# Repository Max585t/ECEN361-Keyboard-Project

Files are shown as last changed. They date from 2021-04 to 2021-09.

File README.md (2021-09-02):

# ECEN361-Keyboard-Project

This project is built on top of Redox by Mattia Dal Ben (https://github.com/mattdibi/redox-keyboard) and KMK by @klardotsh and @kdb424 (https://github.com/KMKfw/kmk_firmware)

## Code
The code I wrote for this project can be found in code.py. This file is what the circuitpython device (Pi Pico in this case) actually runs.

## Modifications
For this project, I had to make modifications to both Redox and KMK. Here are my changes to the Redox base plate.



Here are the changes I made to KMK

Original:
```python
#led.py
import pulseio
...
self.led = pulseio.PWMOut(led_pin)

#kmk_keyboard.py
def init_uart(self, pin, timeout=20):
  if self.is_target:
    return busio.UART(tx=None, rx=pin, timeout=timeout)
  else:
    return busio.UART(tx=pin, rx=None, timeout=timeout)
```
Mine:
```python
#led.py
import pwmio
...
self.led = pwmio.PWMOut(led_pin)
    
#kmk_keyboard.py
def init_uart(self, pin, timeout=20):
  if self.is_target:
    return busio.UART(tx=None, rx=pin[1], timeout=timeout)
  else:
    return busio.UART(tx=pin[0], rx=None, timeout=timeout)
```

## Schematic
Keyboard Schematic
It is important to note that the GND pin on the USB breakout board be connected directly to TP1 and not any of the Pico's other GND pins. If USB ground is not connected to TP1, USB type C will not work. 
Also, the even though the diodes are on the rows, they must be defined in KMK as being on columns. This is because the diode orientation used in the circuit is for pulling pins low, but KMK pulls its pins high. 

## Pictures



note: final base plate not shown


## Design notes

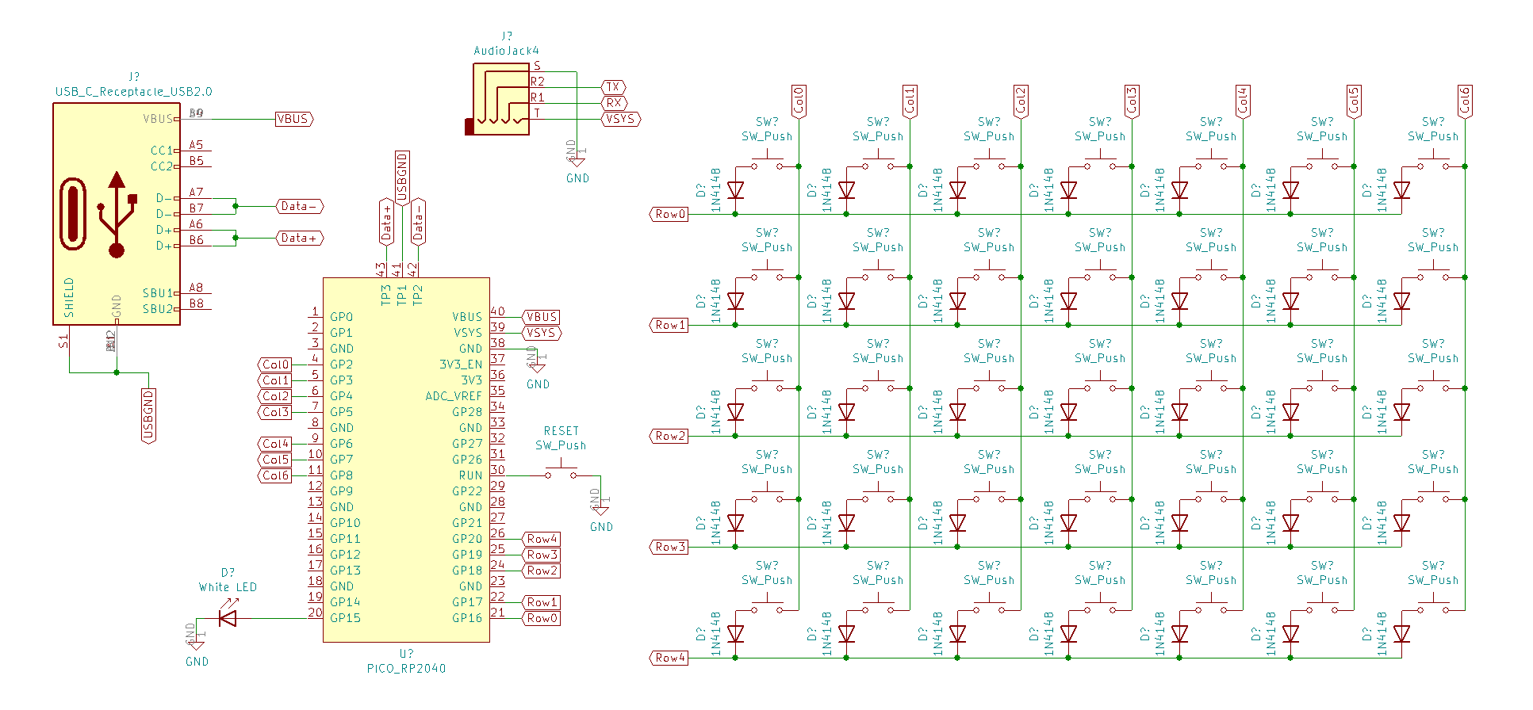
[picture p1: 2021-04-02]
Hardware/Schematics/Keyboard Schematic.png

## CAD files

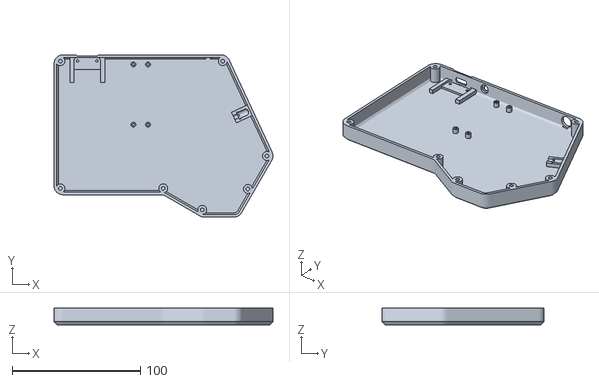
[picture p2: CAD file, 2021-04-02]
Hardware/3D files/bottomL.stl
171.0 x 126.9 x 13.0

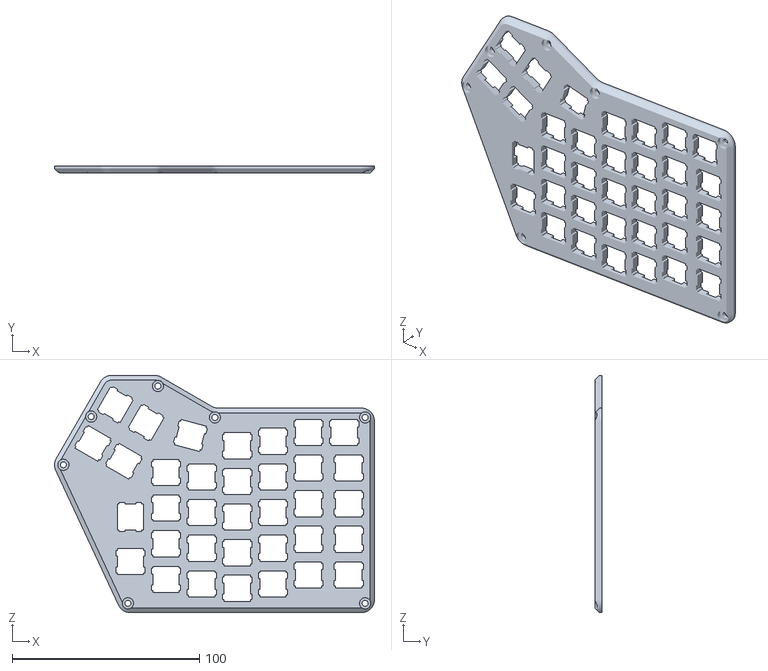
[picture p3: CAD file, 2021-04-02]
Hardware/3D files/PlateL.STL
171.1 x 4.00 x 126.9

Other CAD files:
Hardware/3D files/bottomR.stl
Hardware/3D files/PlateR.STL

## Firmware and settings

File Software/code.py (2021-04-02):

import board
from kmk.keys import KC
from kmk.kmk_keyboard import KMKKeyboard
from kmk.matrix import DiodeOrientation
from kmk.handlers.sequences import send_string
import digitalio

redox_l = KMKKeyboard()

#redox_l.debug_enabled = True
redox_l.col_pins = (board.GP2, board.GP3, board.GP4, board.GP5, board.GP6, board.GP7, board.GP8)
redox_l.row_pins = (board.GP16, board.GP17, board.GP18, board.GP19, board.GP20)
redox_l.diode_orientation = DiodeOrientation.COLUMNS

redox_l.split_type = "UART"
redox_l.uart_pin = (board.GP0, board.GP1) # Must include this to get pico uart to work. kmk_keyboard.py lines 172, 174 changed from ...x=pin, to x=pin[0 or 1]
redox_l.split_flip = True
redox_l.split_offsets = [7, 7, 7, 7, 7]

qt_strg = send_string("quit()")

redox_l.keymap = [
    # Qwerty
    #     ,------------------------------------------------.               ,------------------------------------------------. 
    #     |  esc |   1  |   2  |   3  |   4  |   5  |delete|               |delete|   6  |   7  |   8  |   9  |   0  |  fn  |
    #     |------+------+------+------+------+------+------|               |------+------+------+------+------+------+------|
    #     | tab  |   Q  |   W  |   E  |   R  |   T  |  esc |               | rclck|   Y  |   U  |   I  |   O  |   P  |bckspc|
    #     |------+------+------+------+------+-------------|               |------+------+------+------+------+-------------|
    #     | ctrl |   A  |   S  |   D  |   F  |   G  |  {[  |               | -_   |   H  |   J  |   K  |   L  |   :  |  \|  |
    #     |------+------+------+------+------+------|------|               |------+------+------+------+------+------|------|
    #     | Shift|   Z  |   X  |   C  |   V  |   B  |  }]  |               | +=   |   N  |   M  |  ,<  |  .>  |  ?/  |Shift |
    #     |------+------+------+------+------+------+------|               |------+------+------+------+------+------+------|
    #     | caps |  gui |  alt |tilde |space |bacspc|play  |               | ctrl |  gui |Space |arrowL|arrowD|arrowU|arrowR|
    #     `------------------------------------------------'               `------------------------------------------------'
    [
        KC.ESC,   KC.N1,   KC.N2,   KC.N3,   KC.N4,           KC.N5,   KC.DEL,             KC.N6,         KC.N7,    KC.N8,    KC.N9,    KC.N0,   KC.MINS,  KC.BSPC,
        KC.TAB,   KC.Q,    KC.W,    KC.E,    KC.R,            KC.T,    KC.LALT(KC.A),      KC.LALT(KC.V), KC.Y,     KC.U,     KC.I,     KC.O,    KC.P,     KC.BSLS,
        KC.LCTL,  KC.A,    KC.S,    KC.D,    KC.F,            KC.G,    KC.LBRC,            KC.QUOT,       KC.H,     KC.J,     KC.K,     KC.L,    KC.SCLN,  KC.ENT,
        KC.LSFT,  KC.Z,    KC.X,    KC.C,    KC.V,            KC.B,    KC.RBRC,            KC.EQL,        KC.N,     KC.M,     KC.COMM,  KC.DOT,  KC.SLSH,  KC.MO(1),
        KC.CAPS,  KC.LALT, KC.GRV,  KC.MNU,  KC.LALT(KC.TAB), KC.SPC,  qt_strg,            KC.ENT,        KC.SPC,   KC.RGUI,  KC.LEFT,  KC.DOWN, KC.UP,    KC.RGHT,
    ],
    [
        KC.TRNS,  KC.F1,   KC.F2,   KC.F3,   KC.F4,   KC.F5,   KC.F12,       KC.F6,     KC.F7,    KC.F8,   KC.F9,    KC.F10,  KC.F11,   KC.TRNS,
        KC.TRNS,  KC.TRNS, KC.TRNS, KC.TRNS, KC.TRNS, KC.TRNS, KC.TRNS,      KC.TRNS,   KC.TRNS,  KC.TRNS, KC.TRNS,  KC.TRNS, KC.TRNS,  KC.TRNS,
        KC.TRNS,  KC.TRNS, KC.TRNS, KC.TRNS, KC.TRNS, KC.TRNS, KC.TRNS,      KC.TRNS,   KC.TRNS,  KC.TRNS, KC.TRNS,  KC.TRNS, KC.TRNS,  KC.TRNS,
        KC.TRNS,  KC.TRNS, KC.TRNS, KC.TRNS, KC.TRNS, KC.TRNS, KC.TRNS,      KC.TRNS,   KC.TRNS,  KC.TRNS, KC.TRNS,  KC.TRNS, KC.TRNS,  KC.MO(0),
        KC.TRNS,  KC.TRNS, KC.TRNS, KC.TRNS, KC.TRNS, KC.TRNS, KC.TRNS,      KC.TRNS,   KC.TRNS,  KC.TRNS, KC.TRNS,  KC.TRNS, KC.TRNS,  KC.TRNS,
    ],
]

if __name__ == '__main__':
    led = digitalio.DigitalInOut(board.GP15)
    led.direction = digitalio.Direction.OUTPUT
    led.value = True
    redox_l.go()
